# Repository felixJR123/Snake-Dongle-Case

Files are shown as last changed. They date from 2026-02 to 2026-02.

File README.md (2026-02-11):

# Snake Dongle Case
This is a build guide for the enclosure of the [Snake Dongle](https://github.com/joaopedropio/snake-dongle)

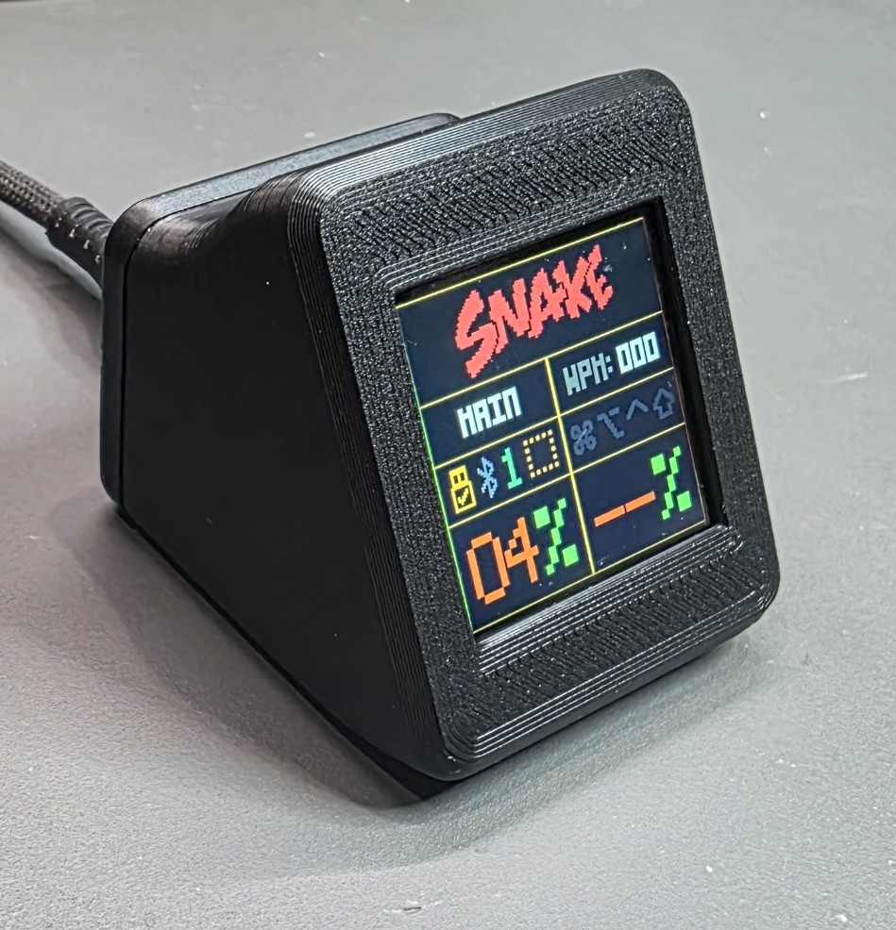
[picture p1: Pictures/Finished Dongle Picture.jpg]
  

There are 2 different types of enclosures for this dongle, one that use the original 6x6x8 tactile switch specified on the snake dongle repo and one that use the switches used in computer mouse. Each of those versions have a variation for #4-20 or M3 screw with plastic threads and another variation for M2 screws and M2 heatset inserts.

## Build Guide for enclosure 
### <ins>Parts needed</ins>

### Enclosure
+ If you choose to use the same parts specified in the dongle repo. The 3D files are located in the folder [Tactile Switches](https://github.com/felixJR123/Snake-Dongle-Case/tree/main/Files/Tactile%20Switches)  
+ If you choose to use the mouse switches, the rest of the parts will be the same as the dongle repo but you will need to purchase 2 mouse switches. The 3D files are located in the folder [Mouse Switches](https://github.com/felixJR123/Snake-Dongle-Case/tree/main/Files/Mouse%20Switches)  
+ There is also a version that uses tactile switches but the screen is the waveshare 1.54in https://www.waveshare.com/1.54inch-LCD-Module.htm The 3D files are located in the folder [Waveshare Screen](https://github.com/felixJR123/Snake-Dongle-Case/tree/main/Files/Waveshare%20Screen)

### Screws
For the M2 versions
| Qty | Description | Sample |
| --- | --- | --- |
| 5 | M2 x 8 thru 12mm long | [Amazon](https://a.co/d/0d4cgYSR) or [Ali Express](https://www.aliexpress.us/item/3256805692722422.html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)|
| 5 | M2 heat set insert with 3-3.2mm outer diameter lenght can vary | [Amazon](https://a.co/d/08Zx6keB) or [Ali Express](https://www.aliexpress.us/item/3256807466816961.html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)|

If the mounting hole in the buzzer is too large M3 x 8mm srew can be used instead of the M2 heat insert and screw

For the #4-20 or M3 plastic screw versions
| Qty | Description | Sample |
| --- | --- | --- |
| 5 | #4-20 or M3 screw for plastic threads 8 thru 12mm long | [Amazon](https://a.co/d/069thOSX) or [Ali Express](https://www.aliexpress.us/item/2255800056366946.html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)|

### Electronics
+ All electronics are the same as on the Snake Dongle repo with the exception of the reset and menu switches.
+ The tactile switch version uses 2 6x6x8 tactile switch [Amazon](https://a.co/d/02oBYbTl) or [Ali Express](https://www.aliexpress.us/item/3256809519260867.html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)\
The mouse switch version uses 2 mouse switches [Amazon](https://a.co/d/0a1DLIsz) or [Ali Express](https://www.aliexpress.us/item/3256804568100432.html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)

Disclosure: I have NO afiliation to Amazon or Aliexpress. The links are only a reference of what to purchase, feel free to browse around.

### <ins>Printed Parts</ins>
Each file contains all part needed for each build, the versions with the mouse switches have 2 extra buttons.  
After choosing which version to build and downloading the file make sure print orientation is correct when compared to the picture below.
+ Supports are not necessary.
+ The screen holder is printed sideways and a brim is recommended for that part since the footprint touching the build plate is small.
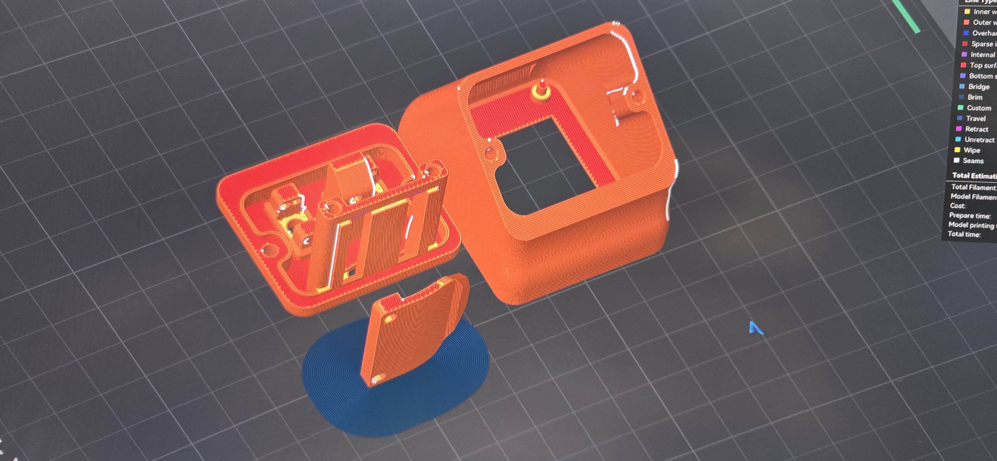
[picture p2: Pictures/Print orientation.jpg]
  

### <ins>Before Assembly</ins>
+ Before assembly make sure all the wiring is complete.
+ The buzzer usually comes with 90 degree header pins pre soldered and it needs to be removed or the buzzer will not fit in the enclosure, also it will be easier for the assembly to solder the wires from the mcu to the back side of the buzzer pcb.
+ Make sure there is enough slack in the wiring from the screen to the mcu.
+ For the version with mouse switches remove supports where the mounting holes are.
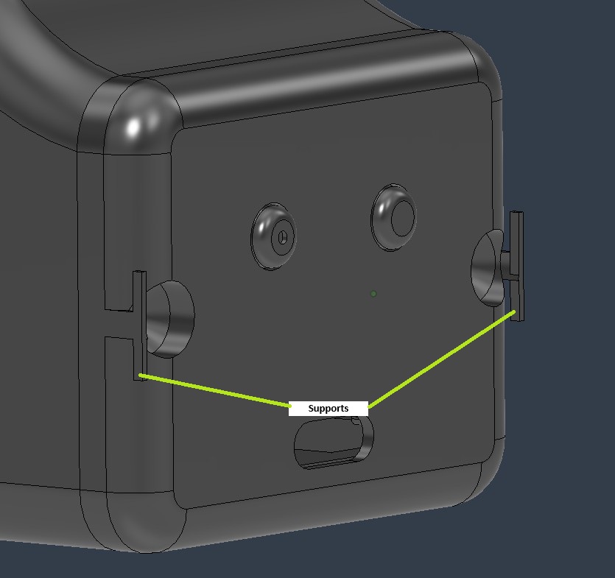
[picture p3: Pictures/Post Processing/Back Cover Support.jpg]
  
+ Depending if you are using a nicenano or a clone check and cut away extra material on the screen holder piece.
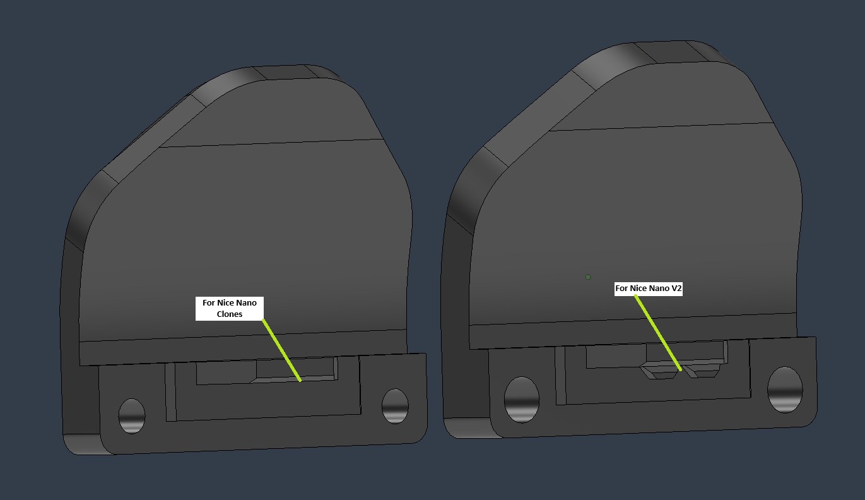
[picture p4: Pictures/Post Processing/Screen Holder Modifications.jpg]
  

### <ins>Assembly</ins>
+ Most assembly instructions are the same for both versions, tactile and mouse switches. The only difference is the way the switches are mounted and the version with mouse switches have 2 extra 3d printed parts for the buttons. 
+ On both versions of the enclosure the switches are secured using pieces of regular 1.75mm 3d printer filament inserted thru a set of holes around where the switches sit.

### After all the electronics have been soldered and tested
1. If you have one of the versions with M2 screws insert the heatset threads.
    + There are 2 in the main body and 2 at the tip of the rear cover where the screen holder goes.
    + If the hole on the buzzer pcb is not too large for an M2 screw then a heatset insert can be placed in the hole where the buzzer mounts, otherwise use an M3 screw threaded into the plastic.
2. Mount the switches to the back of the enclosure.
+ Insert filament pieces thru the holes behind the switches until they bottom out at the end and cut the excess.
    + I found sometimes the filament expands a little where is cut. If the snips are not sharp enough it crushes the filament then is very hard to push it all the way, will slide easier if is cut at an angle.
+ Tactile switch version
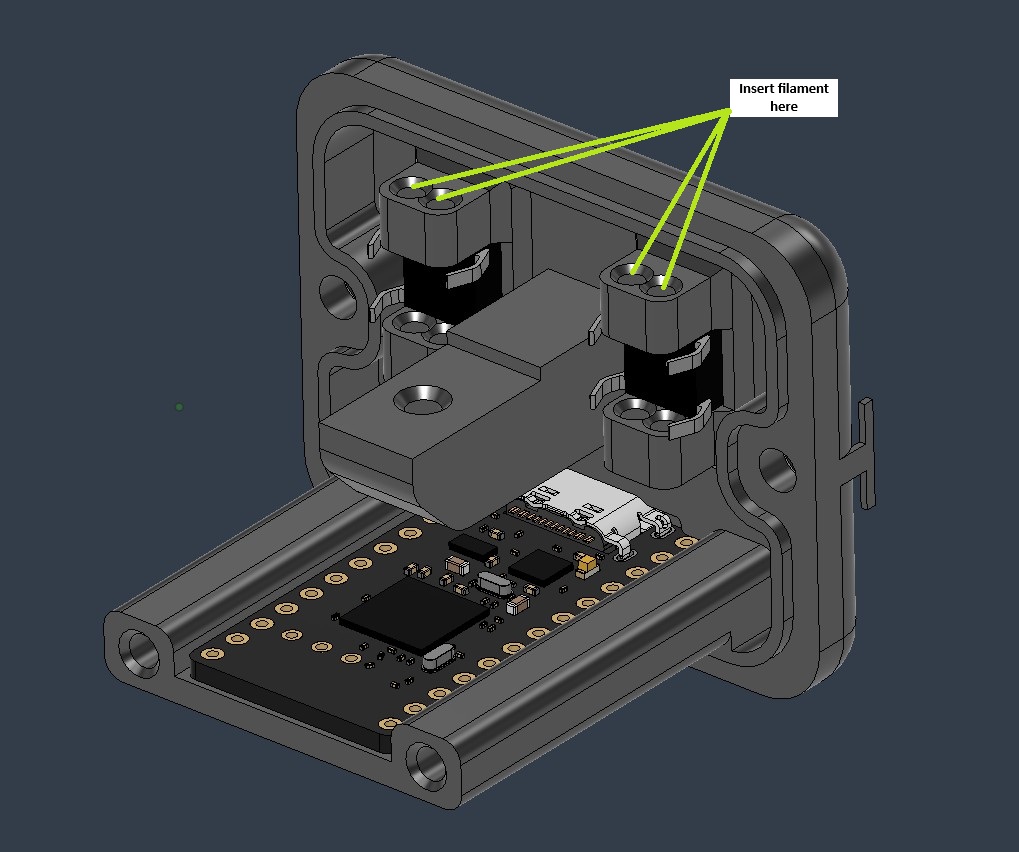
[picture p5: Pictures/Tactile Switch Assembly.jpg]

+ Mouse switch version
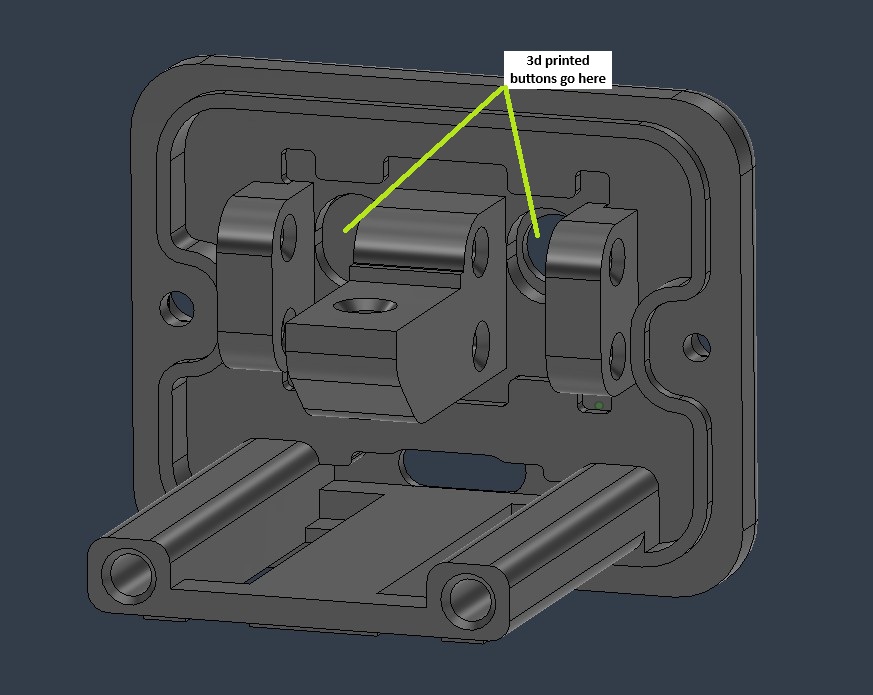
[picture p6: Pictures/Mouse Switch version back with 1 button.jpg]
  
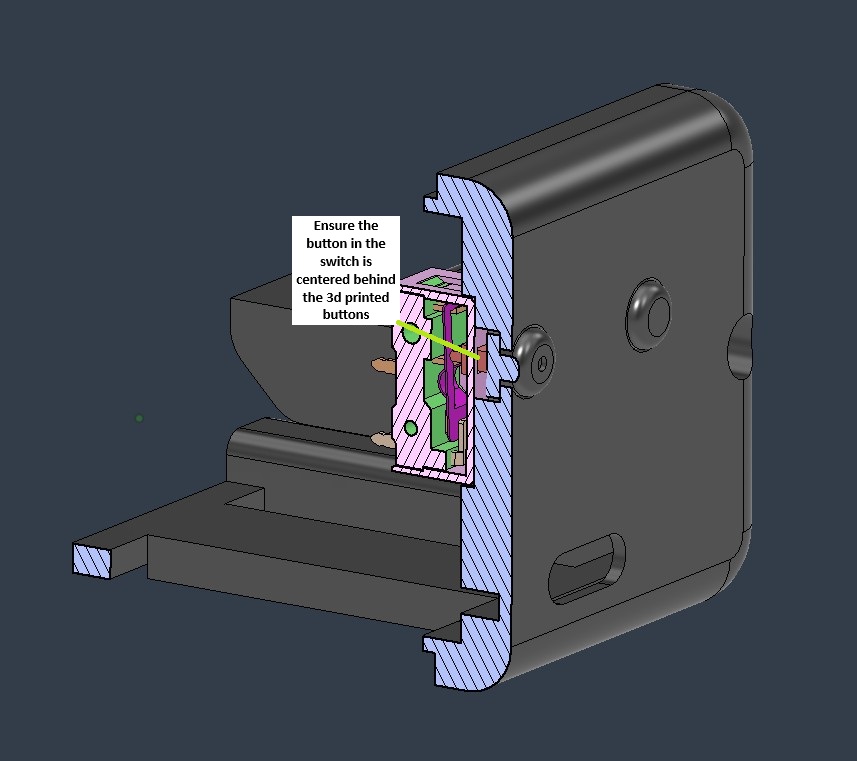
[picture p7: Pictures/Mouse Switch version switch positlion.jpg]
  
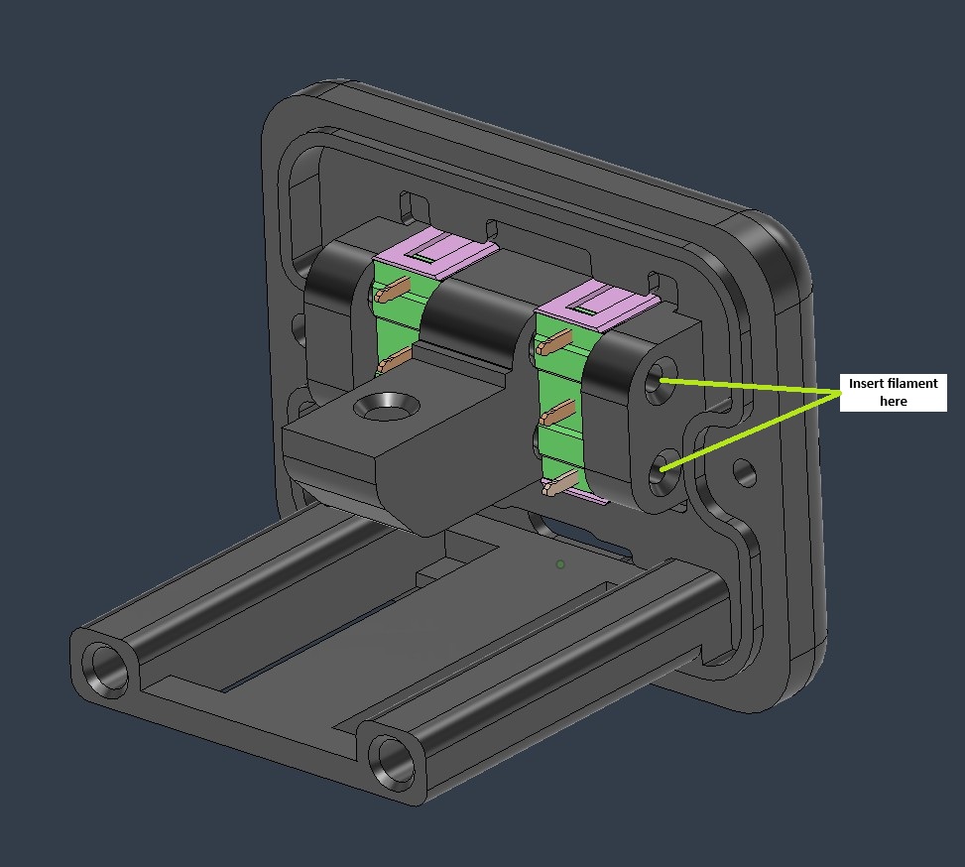
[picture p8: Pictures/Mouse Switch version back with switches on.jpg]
  

<ins>The rest of the steps are the same for all versions</ins>

3. Mount the buzzer and the mcu 
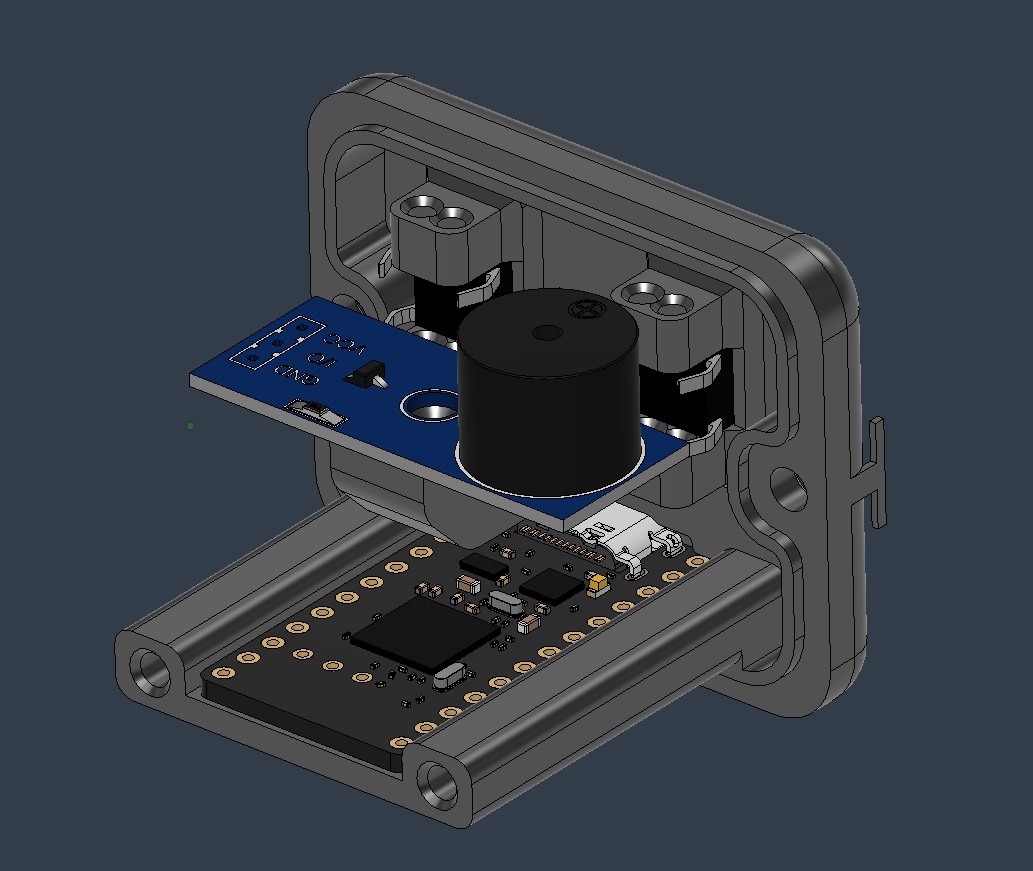
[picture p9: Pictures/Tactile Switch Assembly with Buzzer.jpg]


4. Mount the Screen holder
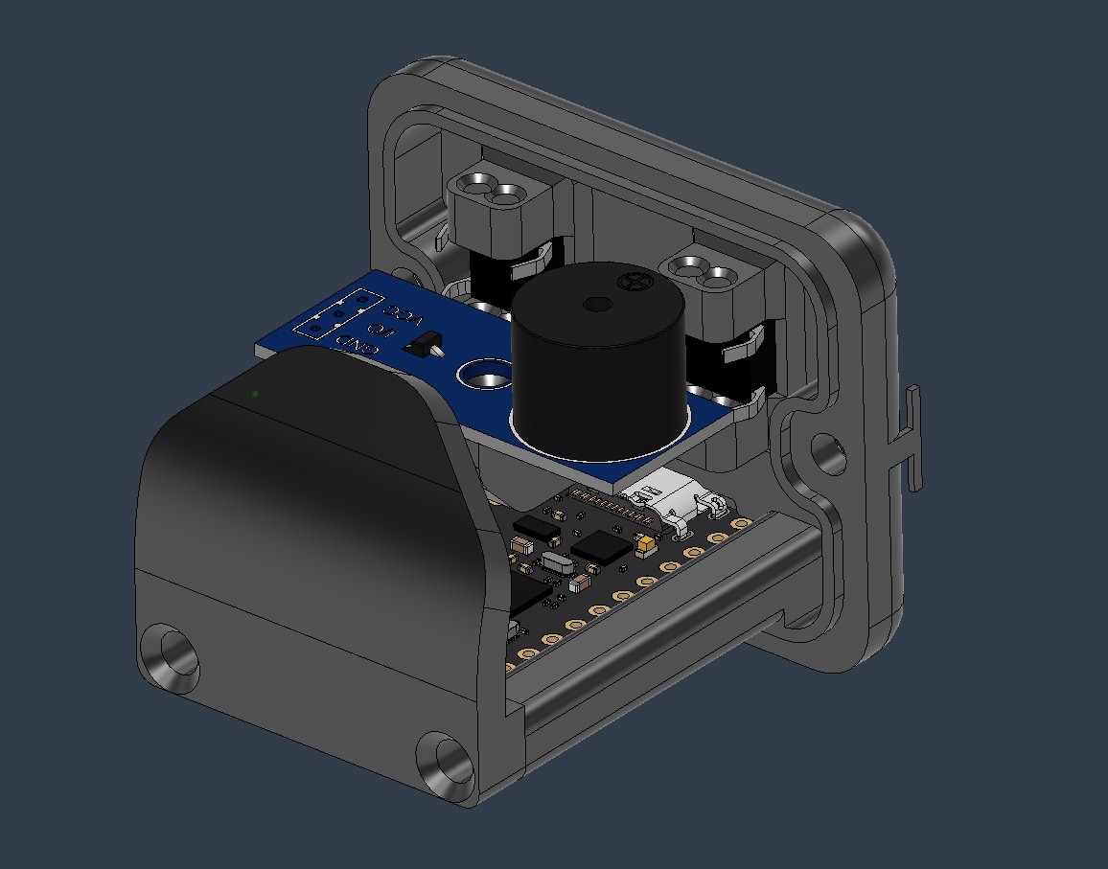
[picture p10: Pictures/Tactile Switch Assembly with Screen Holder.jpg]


5. Insert the screen in the main body with the wires going to the top of the enclosure
    1. The screen slides from the top part of the mounting holes in the back
    2. Then insert the bottom part of the pcb into the slot at the bottom of the main body
    3. Then insert the top holes of the pcb into the pegs at the top of the main body.
    + No glue or fasteners are needed to hold the screen, the back cover will hold it when inserted.
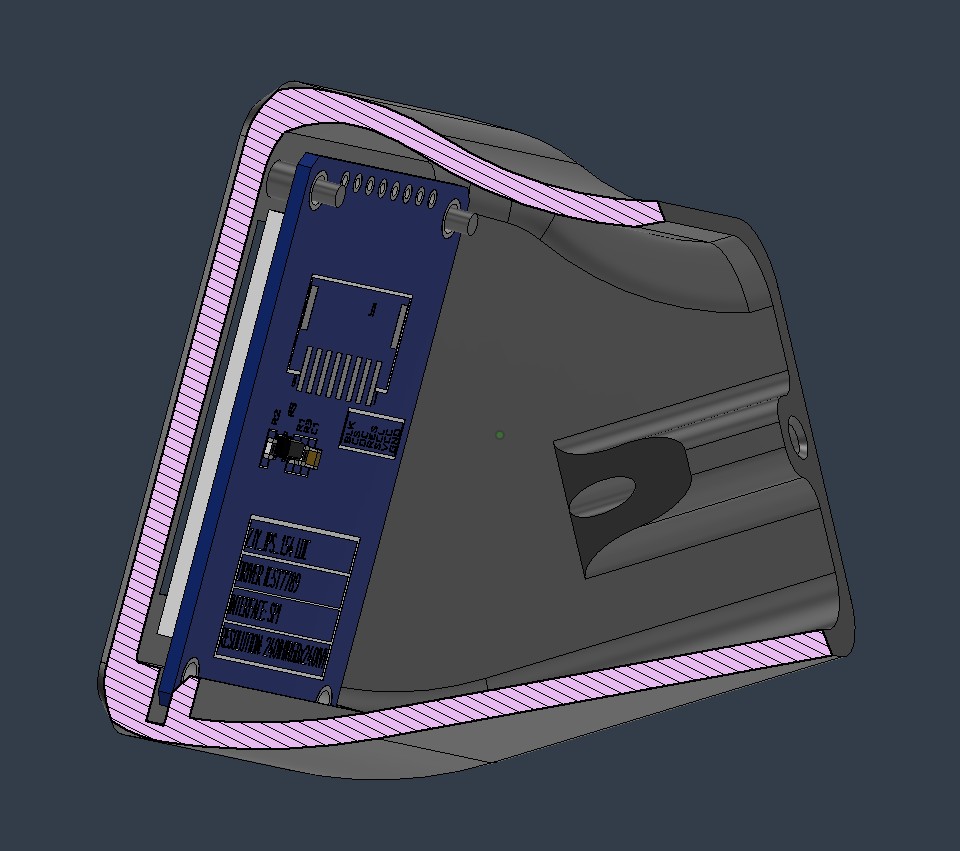
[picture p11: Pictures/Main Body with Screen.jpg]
  

6. Slide the back cover making sure the screen wires are not pressing against the screen holder part (I like to twist the screen wires into a bundle to make this part easier)
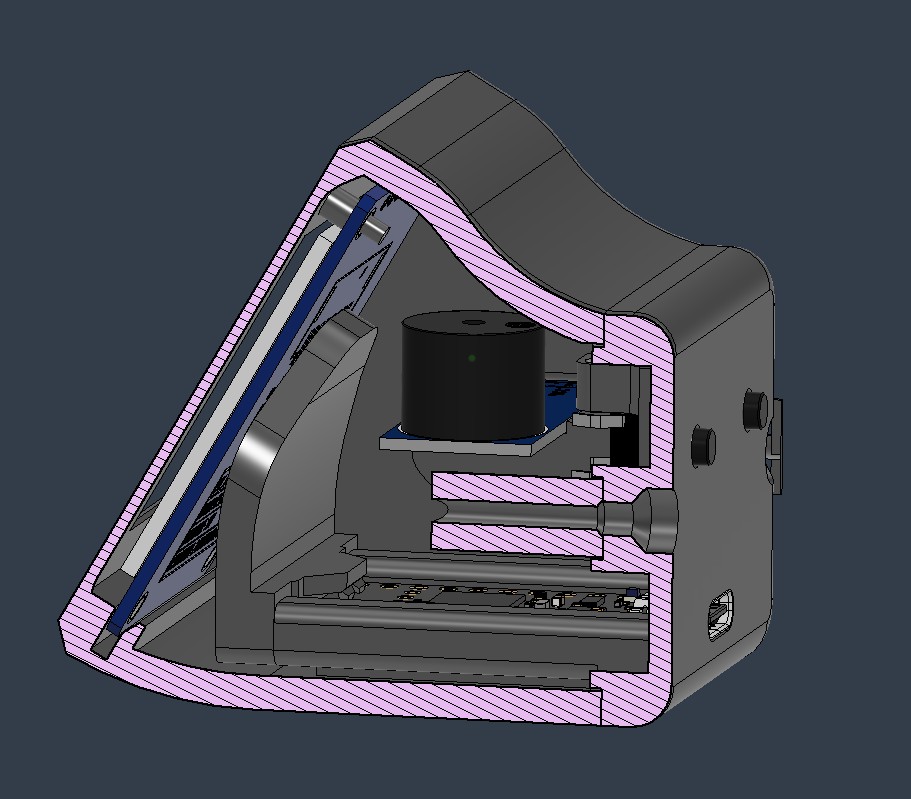
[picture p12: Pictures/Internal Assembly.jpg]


# Credits
+ [joaopedropio](https://github.com/joaopedropio) without him there would no be a dongle to make an enclosure for.  
+ [prospector dongle](https://github.com/carrefinho/prospector) I like the clean design of the enclosure.

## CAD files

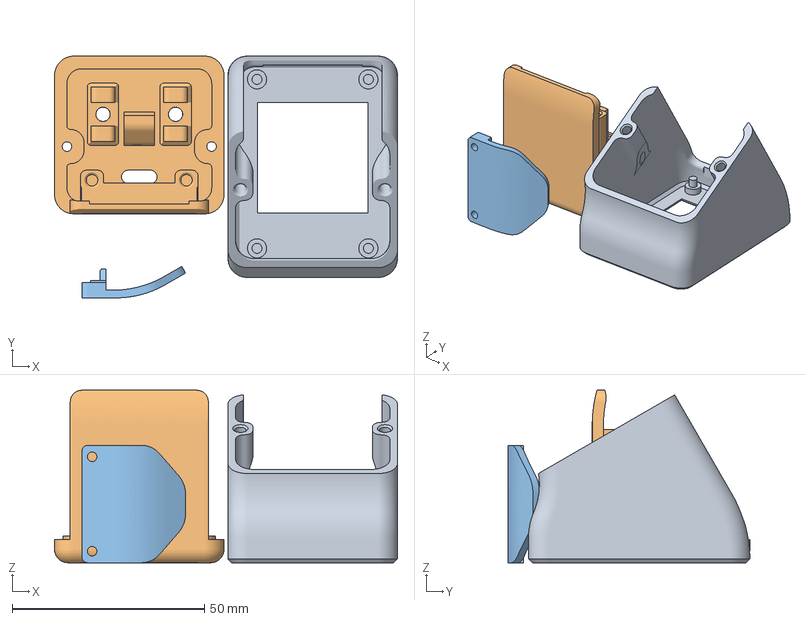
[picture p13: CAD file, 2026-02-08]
Files/Waveshare Screen/Snake Dongle Modified Waveshare with Larger top to fit pin header.3mf
89.3 x 63.0 x 44.9 mm
Main Body Waveshare Screen (6) (1)
Back Cover for Tactile Switches (1) (3) (1) (2)
Screen Holder (1)

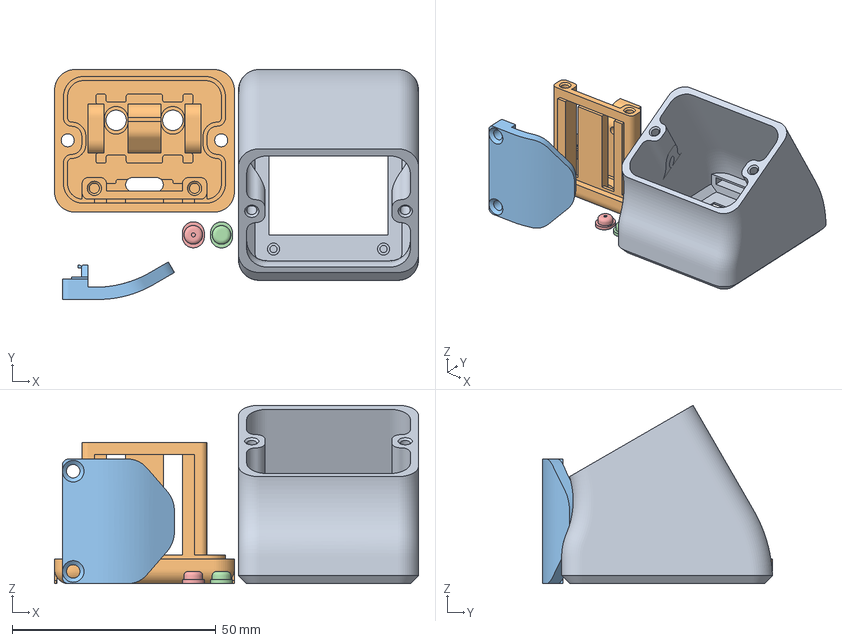
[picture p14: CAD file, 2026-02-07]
Files/Mouse Switches/Snake Dongle Enclosure with mouse switch and #4-20 or M3 plastic screws.3mf
89.3 x 56.4 x 43.8 mm
Main Body
Back Cover
Screen Holder
Button 1
Button 2

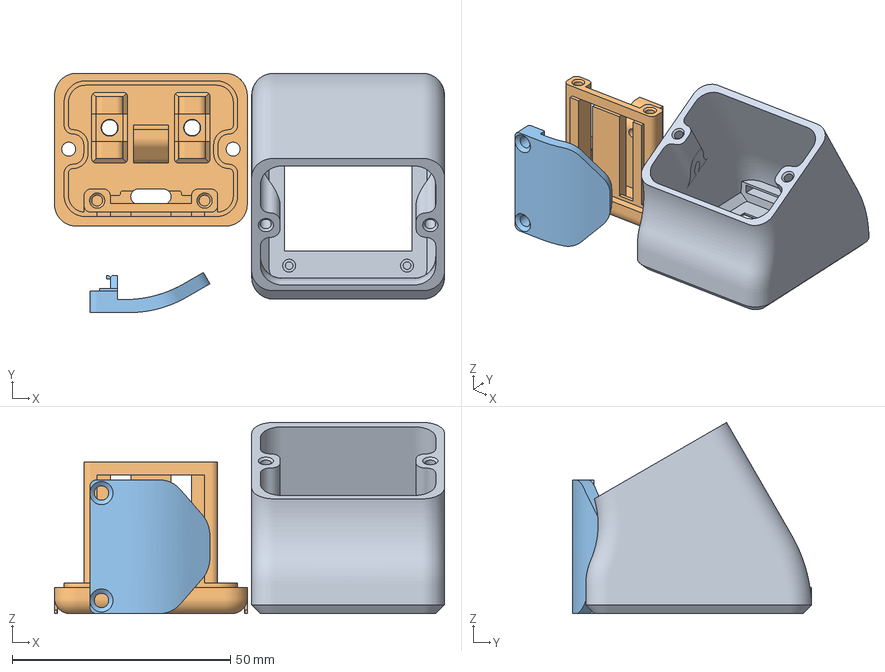
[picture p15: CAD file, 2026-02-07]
Files/Tactile Switches/Snake Dongle Enclosure with tactile switch and #4-20 or M3 plastic screws.3mf
89.3 x 54.8 x 43.8 mm
Main Body
Back Cover for Tactile Switches
Screen Holder

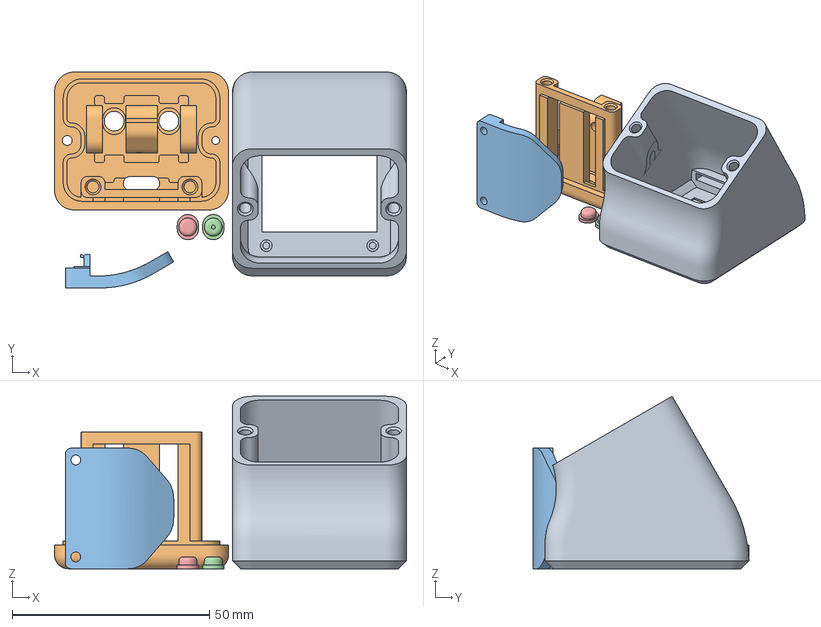
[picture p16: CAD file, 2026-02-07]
Files/Mouse Switches/Snake Dongle Enclosure with mouse switch M2 screws and threaded inserts.3mf
89.3 x 54.8 x 43.8 mm
Main Body
Back Cover
Screen Holder
Button 2
Button 1

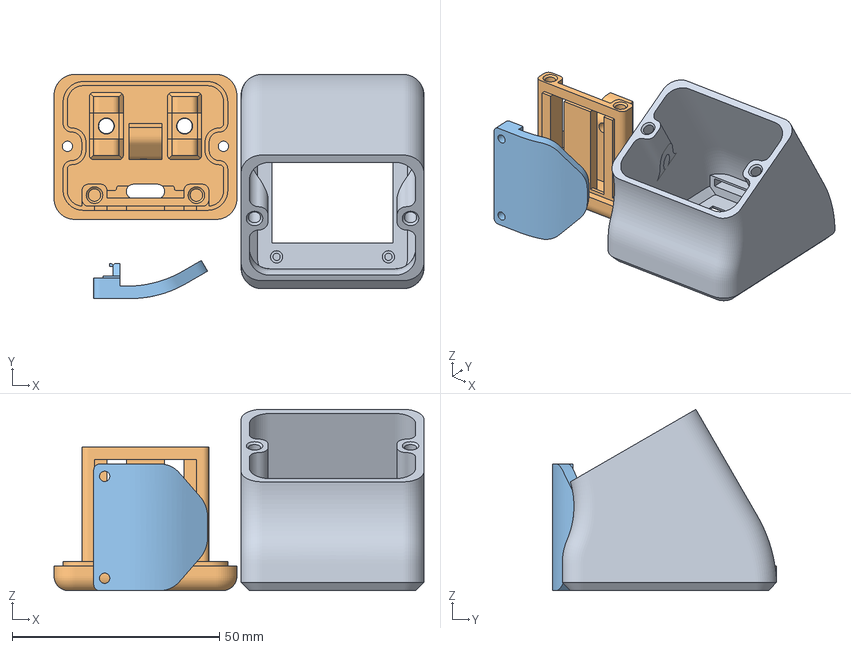
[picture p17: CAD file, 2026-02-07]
Files/Tactile Switches/Snake Dongle Enclosure with tactile switch M2 screws and threaded inserts.3mf
89.3 x 54.1 x 43.8 mm
Main Body
Back Cover for Tactile Switches
Screen Holder

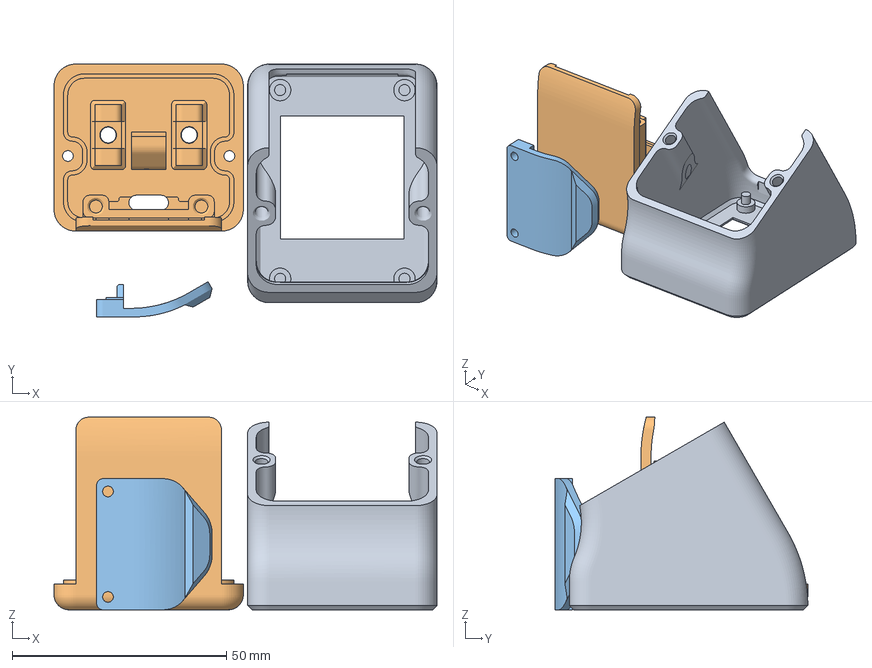
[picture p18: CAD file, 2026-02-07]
Files/Waveshare Screen/Snake Dongle Enclosure Waveshare 1.54in Screen with momentary switch M2 screws and threaded inserts.3mf
89.3 x 59.0 x 44.9 mm
Main Body Waveshare Screen (6)
Back Cover for Tactile Switches (1) (3)
Screen Holder

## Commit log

2026-02-05 Updated 3d files
    [Snake Dongle Case.3mf, Snake Dongle Case.step, Snake Dongle Mouse Switches #4-20 Plastic Screws.3mf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]
2026-02-06 added enclosure for waveshare screen
    [Snake Dongle Modified for Waveshare 1.54 screen(not tested).3mf]
2026-02-06 added print orientation picture
2026-02-06 updated waveshare version with more space in the back to fit better the screen
    [Snake Dongle Modified for Waveshare 1.54 screen (not tested yet).3mf, Snake Dongle Modified for Waveshare 1.54 screen(not tested).3mf]
2026-02-06 updating the design
    [Snake Dongle Mouse Switches M2 Screws.3mf, Snake Dongle Tactile Switches M2 Screws.3mf]
2026-02-07 Updated drawings
    [Snake Dongle Enclosure Waveshare 1.54in Screen with momentary switch M2 screws and threaded inserts.3mf, Snake Dongle Enclosure with momentary switch M2 screws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]
2026-02-07 modified print orientation
    [Snake Dongle Enclosure Waveshare 1.54in Screen with momentary switch M2 screws and threaded inserts.3mf, Snake Dongle Enclosure with momentary switch M2 screws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]
2026-02-07 Worked on readme file
    [Snake Dongle Enclosure with tactile switch M2 screws and threaded inserts.3mf, Snake Dongle Enclosure with tactile switch and #4-20 or M3 plastic screws.3mf.3mf]
2026-02-08 fixed file name
    [Snake Dongle Enclosure with tactile switch and #4-20 or M3 plastic screws.3mf]
2026-02-08 added larger enclosure for waveshare version
    [Snake Dongle Modified Waveshare with Larger top to fit pin header.3mf]
